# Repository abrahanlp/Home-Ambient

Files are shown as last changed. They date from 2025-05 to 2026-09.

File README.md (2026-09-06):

# Home-Ambient
 2-wire smart home thermostat with temperature, humidity, pressure and air quality measurements.

The main target is replace traditional tow wires bimetal thermostats with an intelligent one, cable to integrate with [HomeAssistance](https://www.home-assistant.io/) or works _standalone_ with custom firmware.

## 2-wire classical thermostat replacement
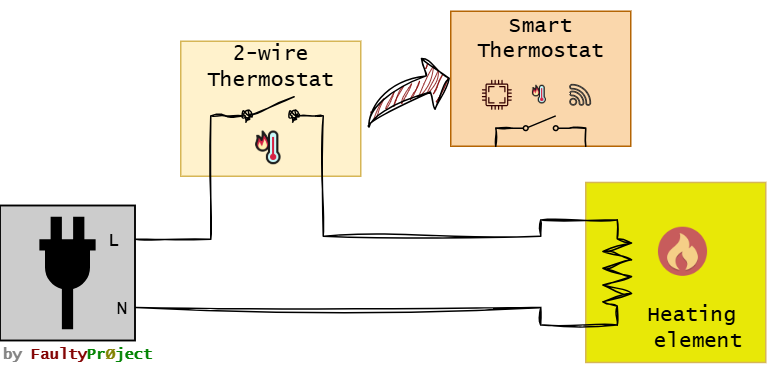
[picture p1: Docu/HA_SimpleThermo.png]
Classic two wire thermostat


### Working principle
Images below explain graphically how this system works.

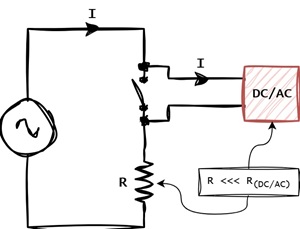
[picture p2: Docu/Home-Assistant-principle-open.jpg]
Home-Ambient principle when load is off

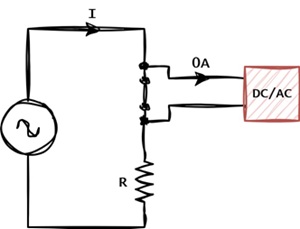
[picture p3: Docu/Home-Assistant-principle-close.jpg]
Home-Ambient principle when load is oon


The main and mandatory system requirement is a big difference between Control an Load level power. While load is some orders of magnitud above, there should not be problem, but is mandatory review every case.

# Product Requirements

| Requirement | Description  | Definition |
|:---:|:---|:---:|
| Temperature	|  Temperature measurement, with minimal interference from the device.	| ±2°C 	|
| Humidity	| Humidity measurement from ambient 	| ±5% 	|
| Air quality	| Air quality estimation by particle detection| Not defined, optional |
| Switch	| 2 pole switch	| >=10A	|
| Switch feedback	| Switch feedback to check operation | Digital or analog |
| HA | Home Assistance integration	| Mandatory	|
| Display | Optional e-Ink display	| No power relevant|
| Autonomy | Capable to operate without power	| At least 2h |

## Hardware architecture
Home-Ambient block diagram is show on image below.

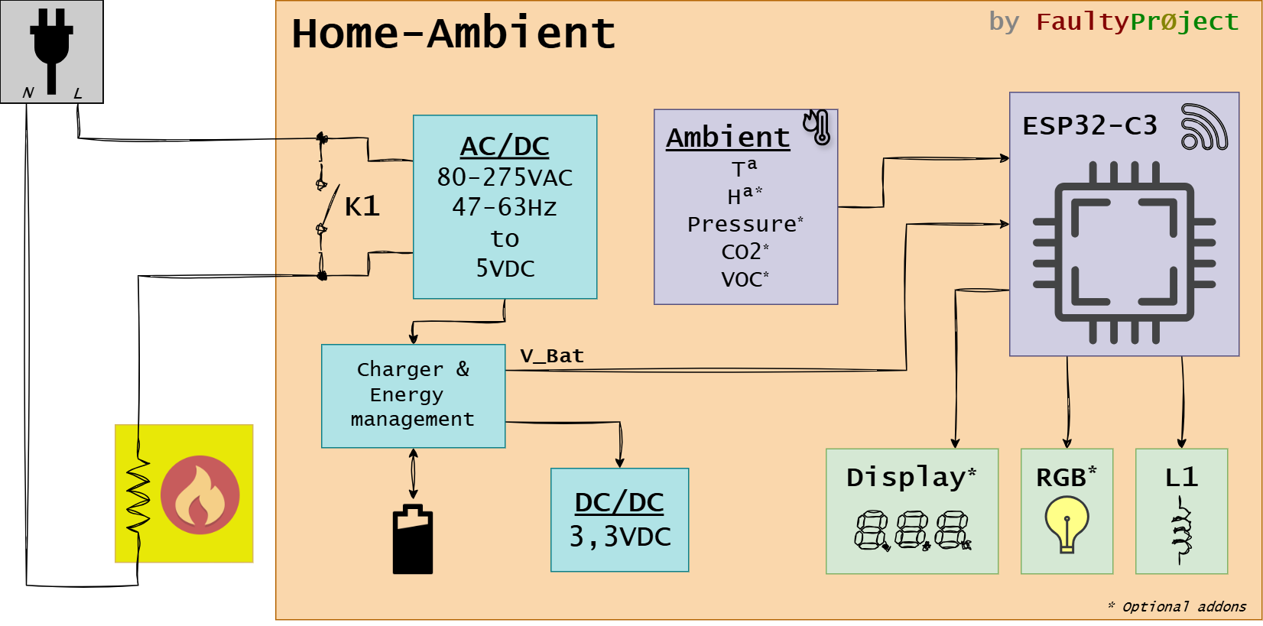
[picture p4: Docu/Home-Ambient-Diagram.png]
Home-Ambient diagram block


The PCB hardware distribution is proposed on next image.

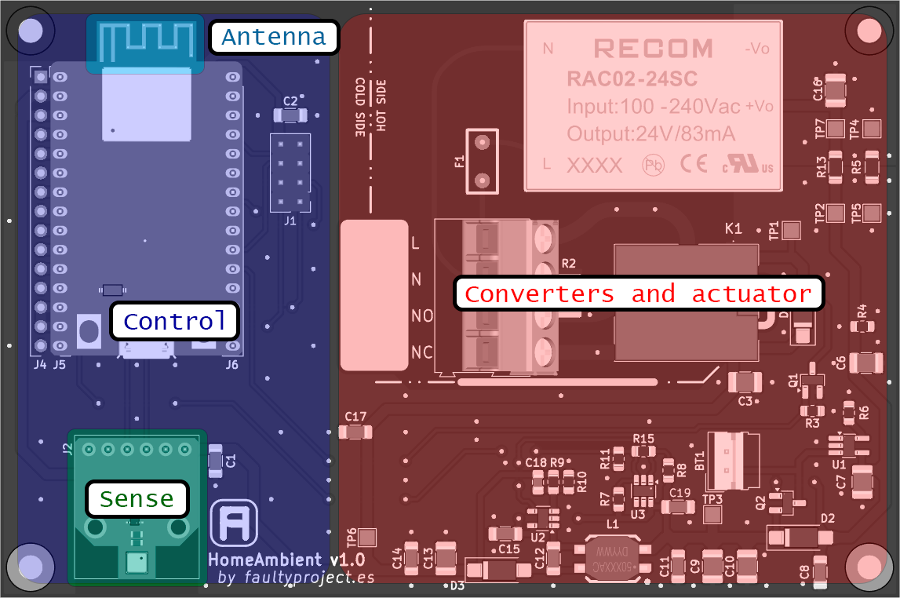
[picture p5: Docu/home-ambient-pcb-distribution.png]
Home-Ambient PCB


### Power supply, SEPIC converter
Energy when the load is activated is provided by a battery. The voltage from this power source varies from above and below 3,3V, so it is neccesary _'boost'_ and _'buck'_ converter.
Here is where the SEPIC converter comes to action, capable of manage both situations at the same time.

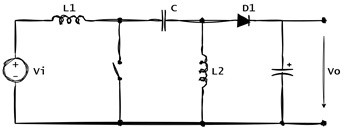
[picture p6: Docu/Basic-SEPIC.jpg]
SEPIC converter schematic


### CPU
The easiest way to integrate custom electronics on _HomeAssistant_ are the [ESPHome](https://esphome.io/) devices. This smart thermostat will be designed around classical [ESP32-C3](https://www.espressif.com/en/products/socs/esp32-c3).

### Sensors and actuators
The BME680 air quality sensor covers all requirements. More info about this component can be found on [Bosch official website](https://www.bosch-sensortec.com/en/products/environmental-sensors/gas-sensors/bme680).

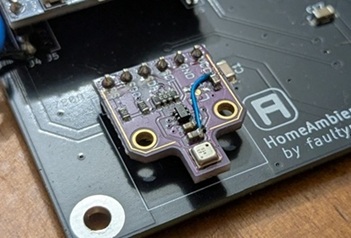
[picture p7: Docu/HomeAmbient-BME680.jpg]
BME680


## Home Assistant integration
As said before, integration is done by [ESPHome](https://esphome.io/), there is no easier way to do this.

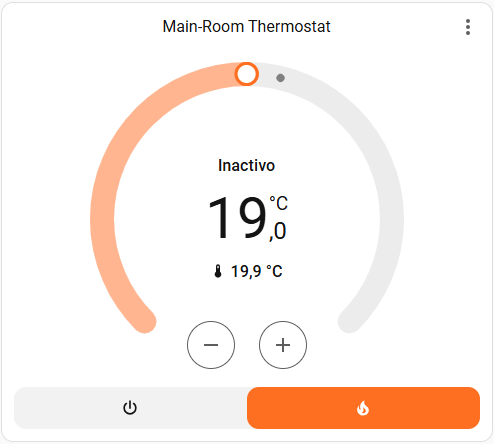
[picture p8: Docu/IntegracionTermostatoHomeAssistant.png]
Home-Ambient integration on Home Assistant


After integration on Home-Assistant, a schedule programmer is implemented using the [Niels Faber](https://github.com/nielsfaber) tools.

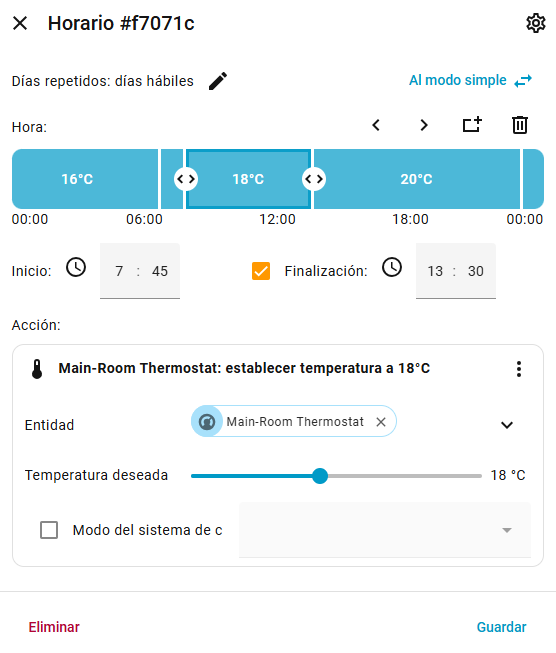
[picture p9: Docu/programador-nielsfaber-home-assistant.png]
Niels Faber scheduler programmer


# More info on [FaultyProject](https://faultyproject.es/)
If you are interested how this project was developed take a look on the next links:
 1. [Introduction](https://faultyproject.es/proyectos/home-ambient/home-ambient-intro/)
 2. [Prototype](https://faultyproject.es/proyectos/home-ambient/home-ambient-prototipo/)
 3. [Schematichs & PCB Design](https://faultyproject.es/proyectos/home-ambient/home-ambient-hardware-esquema-y-pcb/)
 4. [Home Assistant Integration](https://faultyproject.es/proyectos/home-ambient/home-ambient-integracion-con-home-assistant-y-esphome/)
 5. Case design (Future work... )

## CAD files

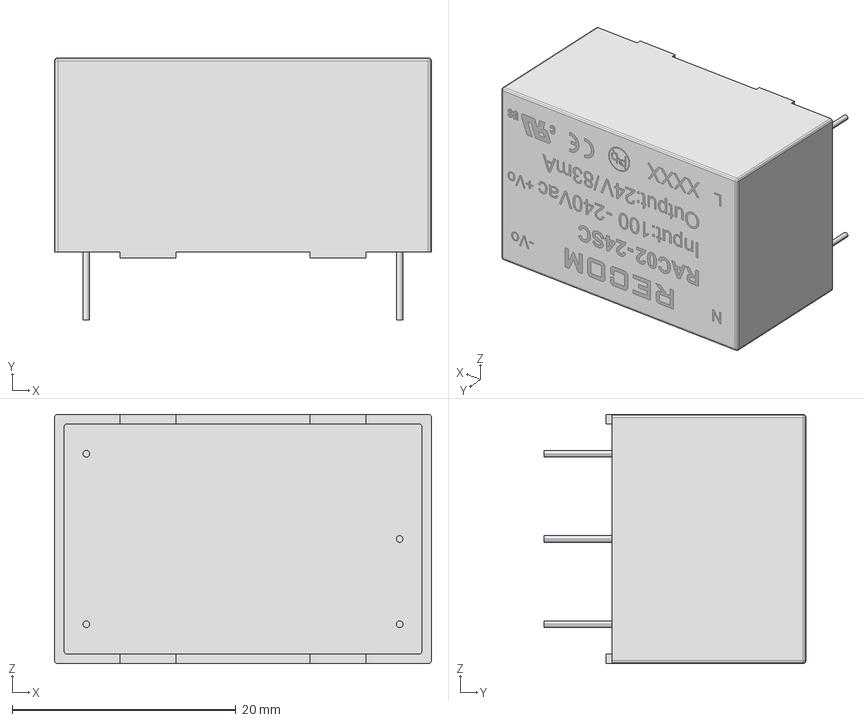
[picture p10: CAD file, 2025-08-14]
Hardware/3D_Model/rac02-05sc.stp
33.7 x 23.5 x 22.3 mm

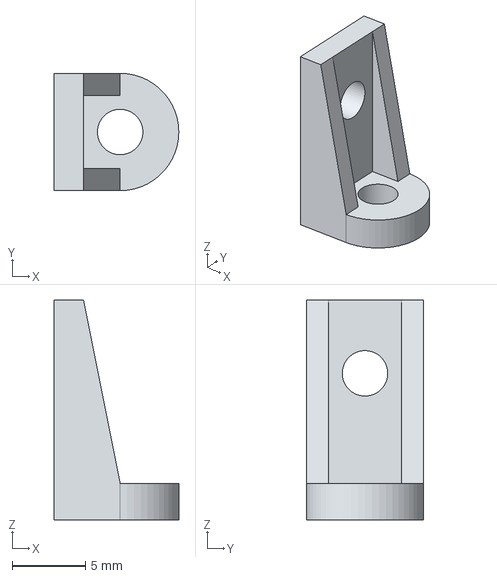
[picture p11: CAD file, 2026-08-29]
Mechanical/HomeAmbient-Fixing.step
8.50 x 8.00 x 15.0 mm

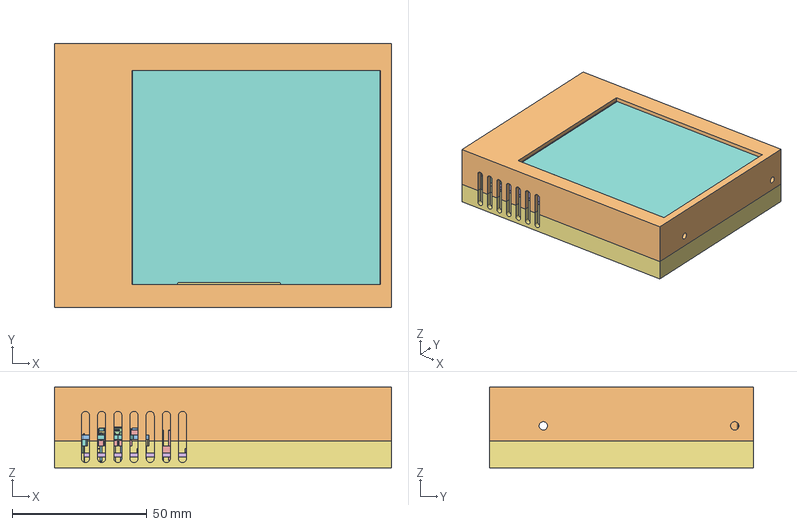
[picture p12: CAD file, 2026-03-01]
Mechanical/HomeAmbient.FCStd
125.0 x 98.0 x 30.0 mm
C_1210_3225Metric
TSOT-23-5
C_1206_3216Metric
C_1206_3216Metric001
PinHeader_2x04_P2.54mm_Vertical
C_1206_3216Metric002
R_1206_3216Metric
SOT-23
R_0805_2012Metric
rac02-05sc_1
rac02-05sc_2
rac02-05sc_3
rac02-05sc_4
rac02-05sc_5
rac02-05sc_6
C_1206_3216Metric003
C_1206_3216Metric004
C_1210_3225Metric001
C_1206_3216Metric005
C_1210_3225Metric002
R_1206_3216Metric001
C_1210_3225Metric003
C_1206_3216Metric006
BME680_PCB
BME680_PCB001
BME680_PCB002
BME680_PCB003
BME680_PCB004
BME680_PCB005
BME680_PCB006
BME680_PCB007
BME680_PCB008
BME680_PCB009
BME680_PCB010
BME680_PCB011
BME680_PCB012
BME680_PCB013
BME680_PCB014
BME680_PCB015
BME680_PCB016
BME680_PCB017
BME680_PCB018
BME680_PCB019
BME680_PCB020
BME680_PCB021
BME680_PCB022
BME680_PCB023
BME680_PCB024
BME680_PCB025
BME680_PCB026
BME680_PCB027
BME680_PCB028
BME680_PCB029
BME680_PCB030
BME680_PCB031
BME680_PCB032
BME680_PCB033
BME680_PCB034
BME680_PCB035
BME680_PCB036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

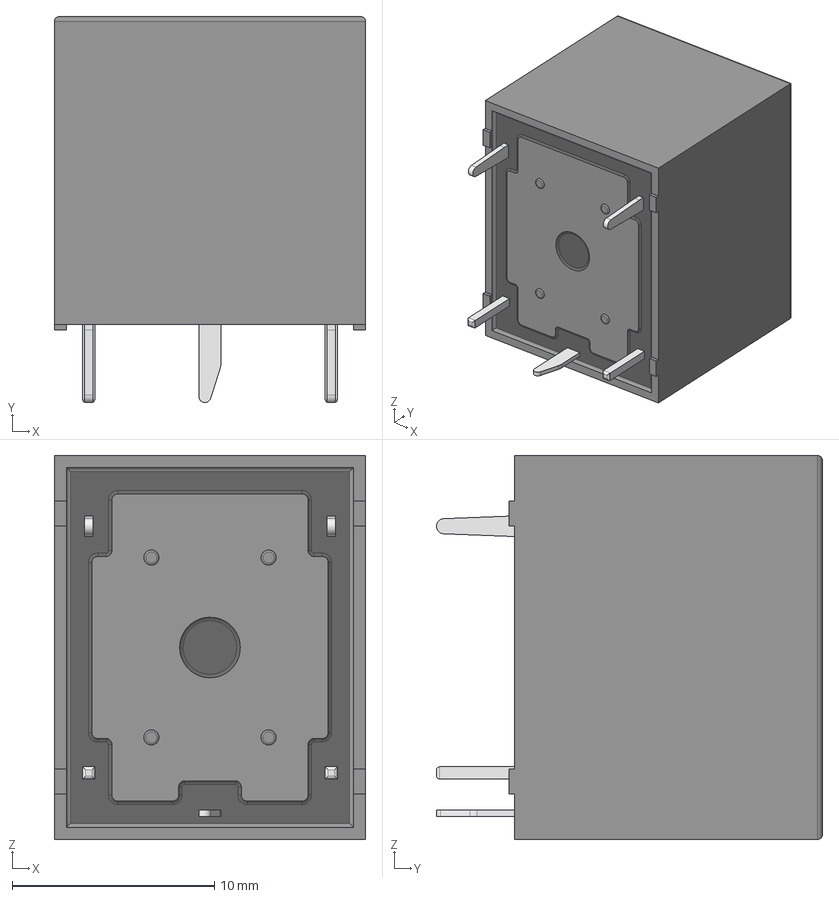
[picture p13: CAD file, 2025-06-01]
Hardware/3D_Model/J1071CS3VDC.36.stp
15.4 x 19.1 x 19.0 mm
J107_Contact Terminal x 2
J107_Common Terminal
J107_Coil Terminal x 2
J107_Body

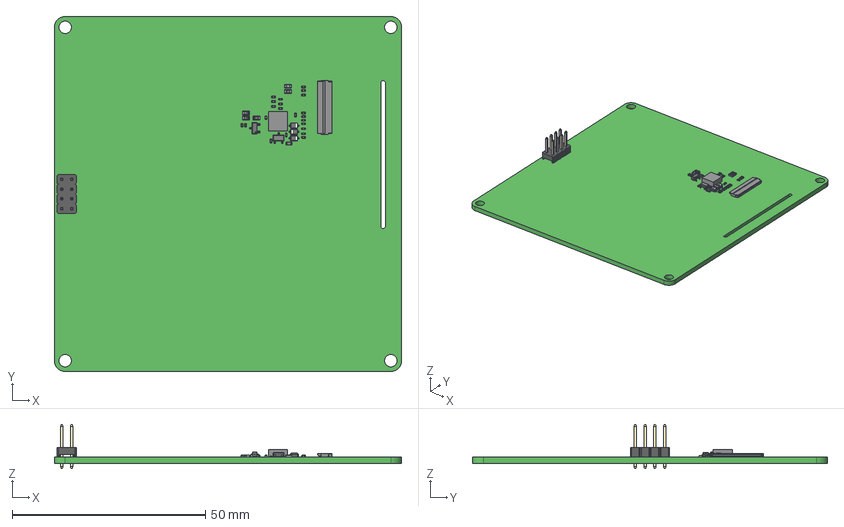
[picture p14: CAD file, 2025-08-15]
Mechanical/WeAct-EpaperModule-4.2 Board 3D.step
89.8 x 91.8 x 11.5 mm
R0603 x 5
Extruded x 6
pin_header_awl254-dg-g08d
User Library-SOT23-3
Mid_Body x 9
Mark x 9
Leader x 3
FH34SRJ-24S-0.5SH_RGB4408131
SOD323 x 3

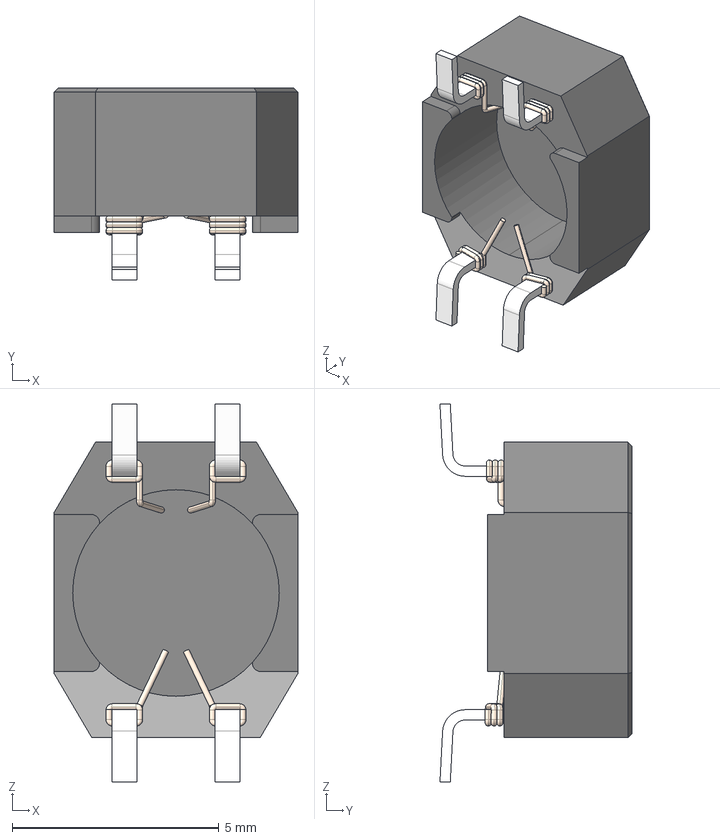
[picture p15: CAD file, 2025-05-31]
Hardware/3D_Model/5000AC.STEP
5.90 x 4.65 x 9.15 mm
mps_mag_5000AC_smt_a
mps_mag_5000AC_smt_a002
mps_mag_5000AC_smt_a003
mps_mag_5000AC_smt_a004
mps_mag_5000AC_smt_a005

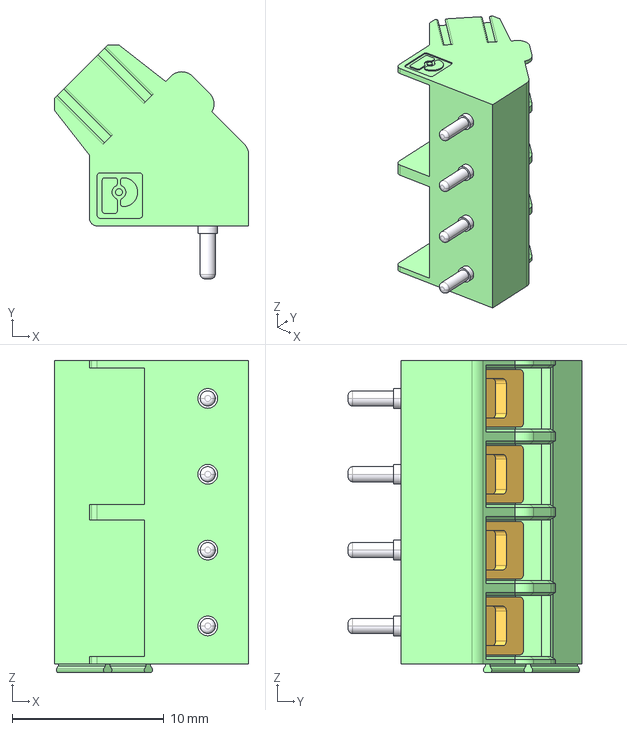
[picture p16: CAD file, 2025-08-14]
Hardware/3D_Model/1988820.stp
12.8 x 15.4 x 20.6 mm

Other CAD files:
Mechanical/HomeAmbient-Fixing.stl

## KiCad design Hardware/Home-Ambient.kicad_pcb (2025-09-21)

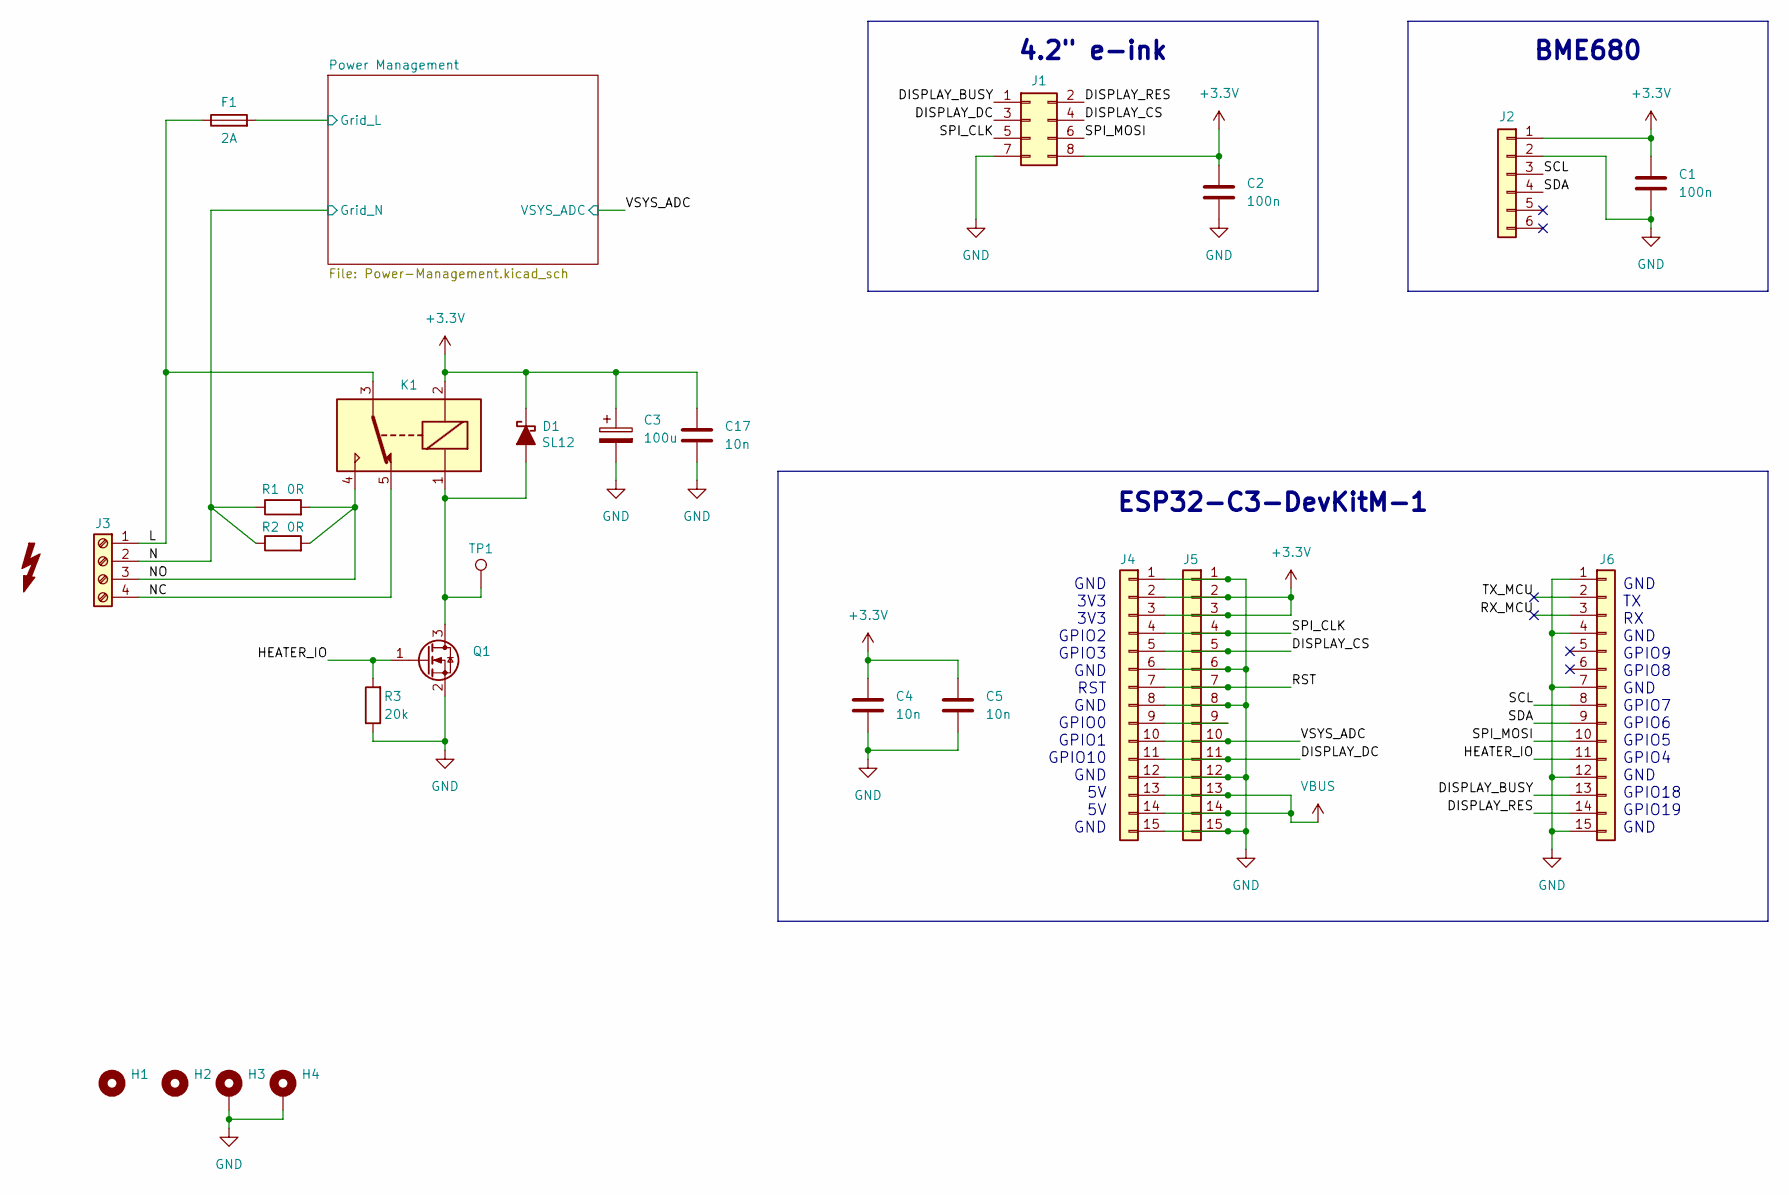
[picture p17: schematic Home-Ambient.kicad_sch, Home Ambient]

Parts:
C1, C2: 100n; C_1206_3216Metric_Pad1.33x1.80mm_HandSolder
C3: 100u; C_1210_3225Metric_Pad1.33x2.70mm_HandSolder
C4, C5, C17: 10n; C_1206_3216Metric_Pad1.33x1.80mm_HandSolder
D1: SL12; D_SMA_Handsoldering
F1: 2A; 0697H____
H1, H2: MountingHole; MountingHole_3.2mm_M3
H3, H4: MountingHole_Pad; MountingHole_3.2mm_M3_Pad_TopBottom
J1: Conn_02x05_Odd_Even; PinHeader_2x04_P2.54mm_Vertical
J2: Conn_01x06; PinHeader_1x06_P2.54mm_Vertical
J3: Screw_Terminal_01x04; TerminalBlock_Altech_AK300-4_P5.00mm
J4, J5, J6: Conn_01x15; PinHeader_1x15_P2.54mm_Vertical
K1: Relay_SPDT; J1071CS3VDC36
Q1: SSF2320Y; SOT-23_Handsoldering
R1, R2: 0R; R_1812_4532Metric_Pad1.30x3.40mm_HandSolder
R3: 20k; R_0805_2012Metric_Pad1.20x1.40mm_HandSolder
TP1: TestPoint_Pad_2.0x2.0mm

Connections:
+3.3V: C1.1, C2.1, C3.1, C4.1, C5.1, C17.1, D1.1 (K), J1.8, J2.1, J4.2, J4.3, J5.2, J5.3, K1.2; also elsewhere on the board
/DISPLAY_BUSY: J1.1, J6.13
/DISPLAY_CS: J1.4, J4.5, J5.5
/DISPLAY_DC: J1.3, J4.11, J5.11
/DISPLAY_RES: J1.2, J6.14
/HEATER_IO: J6.11, Q1.1 (G), R3.2
/L: F1.1, J3.1, K1.3
/N: J3.2, R1.1, R2.1; also elsewhere on the board
/NC: J3.4, K1.5
/NO: J3.3, K1.4, R1.2, R2.2
/Power Management/Grid_L: F1.2; also elsewhere on the board
/RST: J4.7, J5.7
/RX_MCU: J6.3
/SCL: J2.3, J6.8
/SDA: J2.4, J6.9
/SPI_CLK: J1.5, J4.4, J5.4
/SPI_MOSI: J1.6, J6.10
/TX_MCU: J6.2
/VSYS_ADC: J4.10, J5.10; also elsewhere on the board
GND: C1.2, C2.2, C3.2, C4.2, C5.2, C17.2, H3.1, H4.1, J1.7, J2.2, J4.1, J4.6, J4.8, J4.12, J4.15, J5.1, J5.6, J5.8, J5.12, J5.15, J6.1, J6.4, J6.7, J6.12, J6.15, Q1.2 (S), R3.1; also elsewhere on the board
unnamed: D1.2 (A), K1.1, Q1.3 (D), TP1.1
unnamed: J4.9, J5.9
VBUS: J4.13, J4.14, J5.13, J5.14

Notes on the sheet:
BME680
4.2" e-ink
GND TX RX GND GPIO9 GPIO8 GND GPIO7 GPIO6 GPIO5 GPIO4 GND GPIO18 GPIO19 GND
GND 3V3 3V3 GPIO2 GPIO3 GND RST GND GPIO0 GPIO1 GPIO10 GND 5V 5V GND
ESP32-C3-DevKitM-1

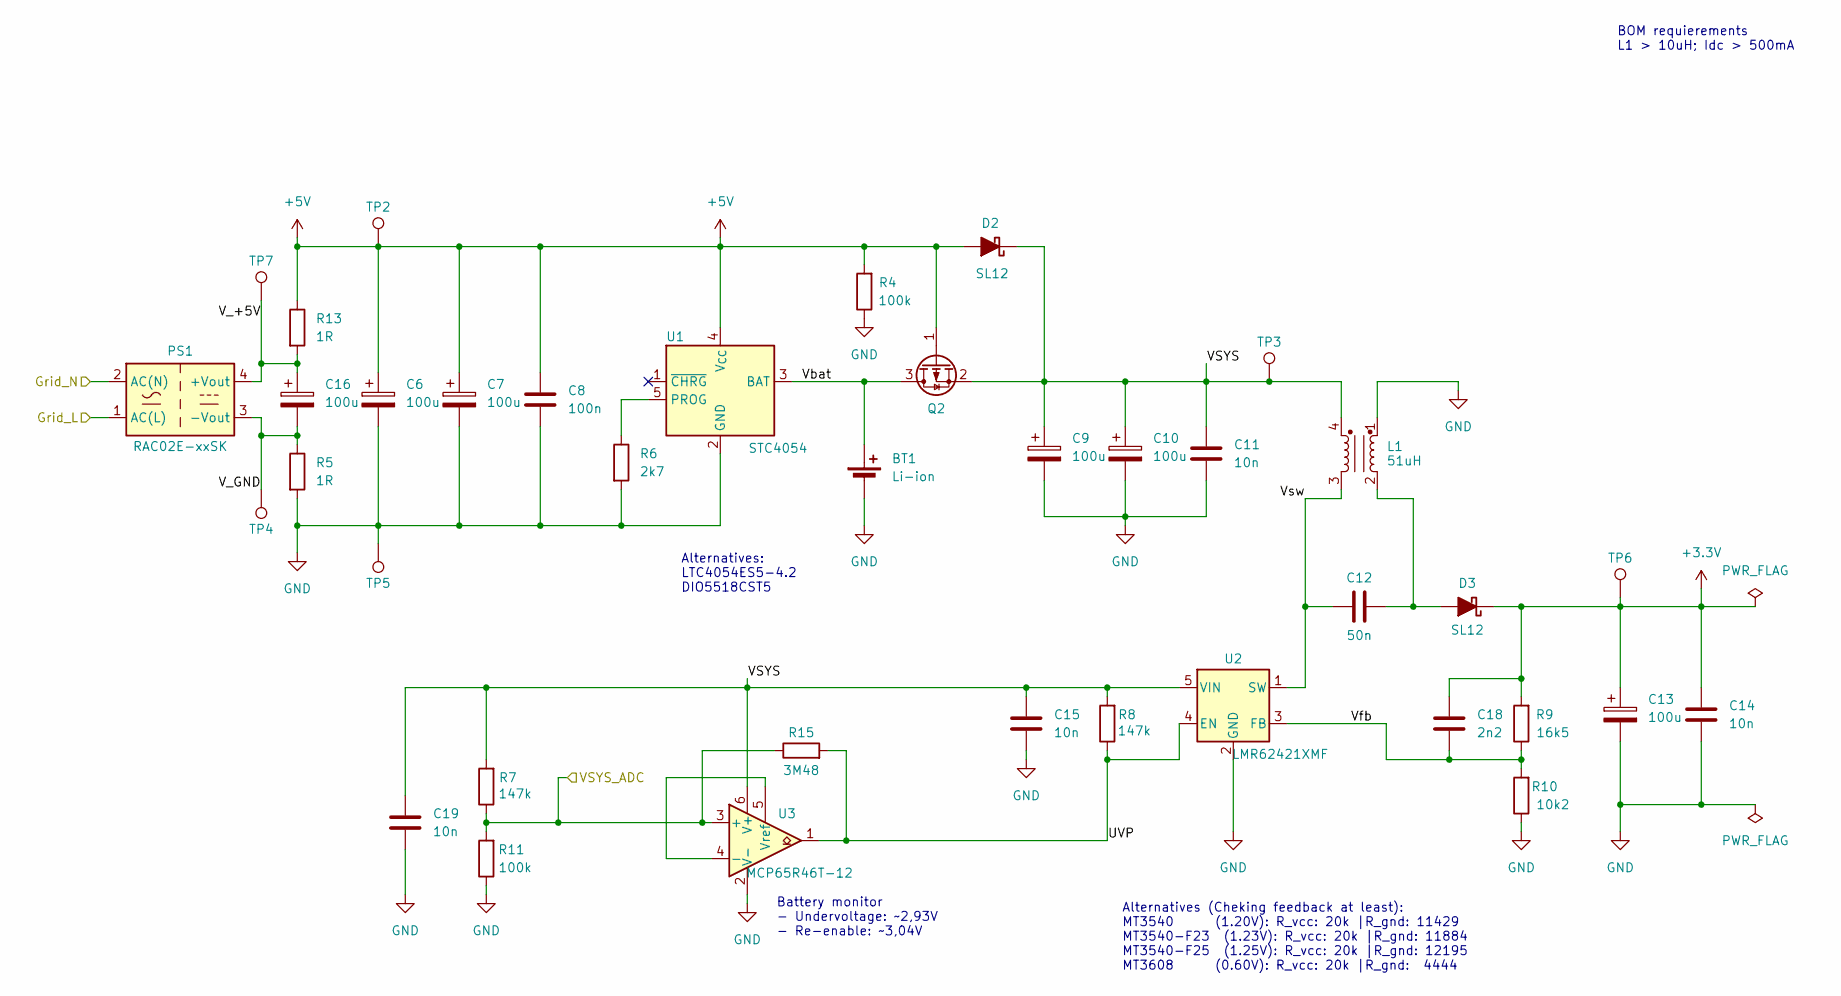
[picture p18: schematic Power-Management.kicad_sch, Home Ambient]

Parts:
BT1: Li-ion; Molex_SL_171971-0002_1x02_P2.54mm_Vertical
C6, C7, C9, C10, C13, C16: 100u; C_1210_3225Metric_Pad1.33x2.70mm_HandSolder
C8: 100n; C_1206_3216Metric_Pad1.33x1.80mm_HandSolder
C11, C14, C15, C19: 10n; C_1206_3216Metric_Pad1.33x1.80mm_HandSolder
C12: 50n; C_1206_3216Metric_Pad1.33x1.80mm_HandSolder
C18: 2n2; C_0805_2012Metric_Pad1.18x1.45mm_HandSolder
D2, D3: SL12; D_SMA_Handsoldering
L1: 51uH; Murata_5000A
PS1: RAC02E-xxSK; RAC02E-K
Q2: DMP31D1U-7; SOT-23_Handsoldering
R4, R11: 100k; R_0805_2012Metric_Pad1.20x1.40mm_HandSolder
R5, R13: 1R; R_1206_3216Metric_Pad1.30x1.75mm_HandSolder
R6: 2k7; R_0805_2012Metric_Pad1.20x1.40mm_HandSolder
R7, R8: 147k; R_0805_2012Metric_Pad1.20x1.40mm_HandSolder
R9: 16k5; R_0805_2012Metric_Pad1.20x1.40mm_HandSolder
R10: 10k2; R_0805_2012Metric_Pad1.20x1.40mm_HandSolder
R15: 3M48; R_0805_2012Metric_Pad1.20x1.40mm_HandSolder
TP2, TP3, TP4, TP5, TP6, TP7: TestPoint_Pad_2.0x2.0mm
U1: STC4054; TSOT-23-5_HandSoldering
U2: LMR62421XMF; SOT-23-5_HandSoldering
U3: MCP65R46T-12; SOT-23-6_Handsoldering

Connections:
+3.3V: C13.1, C14.1, C18.1, D3.1 (K), R9.2, TP6.1; also elsewhere on the board
+5V: C6.1, C7.1, C8.1, D2.2 (A), Q2.1 (G), R4.2, R13.1, TP2.1, U1.4 (V_{CC})
/N: PS1.2 (AC(N)); also elsewhere on the board
/Power Management/Grid_L: PS1.1 (AC(L)); also elsewhere on the board
/Power Management/UVP: R8.1, R15.2, U2.4 (EN), U3.1
/Power Management/VSYS: C9.1, C10.1, C11.1, C15.1, C19.1, D2.1 (K), L1.4, Q2.2 (S), R7.2, R8.2, TP3.1, U2.5 (VIN), U3.6 (V+)
/Power Management/V_+5V: C16.1, PS1.4 (+Vout), R13.2, TP7.1
/Power Management/V_GND: C16.2, PS1.3 (-Vout), R5.1, TP4.1
/Power Management/Vbat: BT1.1 (+), Q2.3 (D), U1.3 (BAT)
/Power Management/Vfb: C18.2, R9.1, R10.2, U2.3 (FB)
/Power Management/Vsw: C12.1, L1.3, U2.1 (SW)
/VSYS_ADC: R7.1, R11.2, R15.1, U3.3 (+); also elsewhere on the board
GND: BT1.2 (-), C6.2, C7.2, C8.2, C9.2, C10.2, C11.2, C13.2, C14.2, C15.2, C19.2, L1.1, R4.1, R5.2, R6.2, R10.1, R11.1, TP5.1, U1.2 (GND), U2.2 (GND), U3.2 (V-); also elsewhere on the board
unnamed: C12.2, D3.2 (A), L1.2
unnamed: R6.1, U1.5 (PROG)
unnamed: U3.4 (-), U3.5 (Vref)

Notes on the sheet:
Battery monitor - Undervoltage: ~2,93V - Re-enable: ~3,04V
Alternatives: LTC4054ES5-4.2 DIO5518CST5
Alternatives (Cheking feedback at least): MT3540 (1.20V): R_vcc: 20k |R_gnd: 11429 MT3540-F23 (1.23V): R_vcc: 20k |R_gnd: 11884 MT3540-F25 (1.25V): R_vcc: 20k |R_gnd: 12195 MT3608 (0.60V): R_vcc: 20k |R_gnd: 4444
BOM requierements L1 > 10uH; Idc > 500mA

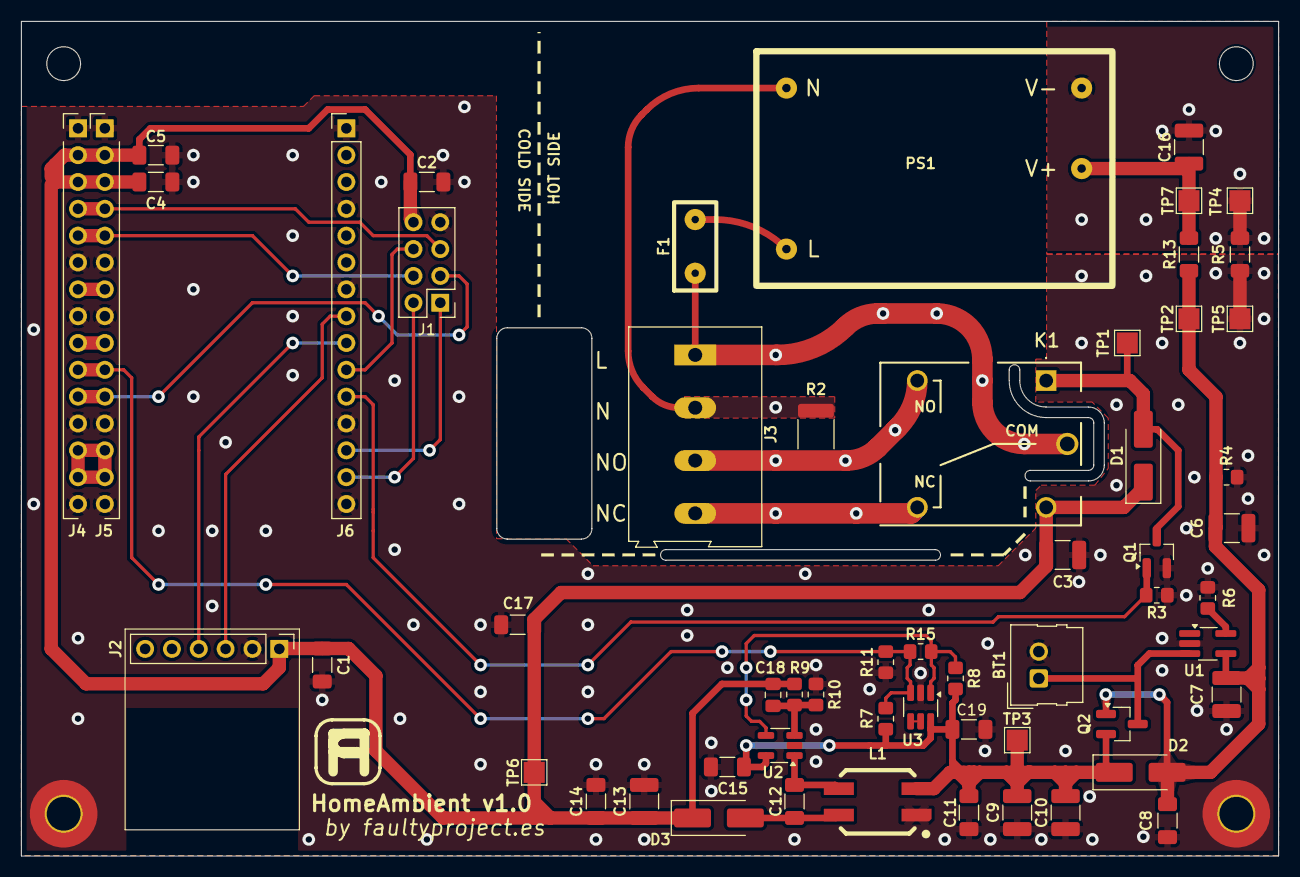
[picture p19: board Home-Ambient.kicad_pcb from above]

Board: 2 copper layers, 119.0 x 79.0 mm, 62 parts (1 on the bottom side), 32 nets.

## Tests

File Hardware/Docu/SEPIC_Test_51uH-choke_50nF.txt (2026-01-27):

Von 3
Voff 2.9

#Relay
Vin;Iin;Vo;Io
3.0;0.169;3.28;0.112
3.2;0.158;3.28;0.112
3.5;0.145;3.28;0.113
4.0;0.128;3.28;0.113
4.5;0.115;3.28;0.114
5.0;0.106;3.28;0.114
5.5;0.098;3.28;0.114

#13ohm
Vin;Iin;Vo;Io
3.00;0.404;3.28;0.226
3.05;0.395;3.28;0.226
3.5;0.333;3.28;0.226
4.0;0.285;3.28;0.226
4.5;0.250;3.28;0.226
5.0;0.224;3.28;0.226
5.5;0.204;3.28;0.226

#6.5ohm
Vin;Iin;Vo;Io
4.5;0.680;3.28;0.480
5.0;0.565;3.28;0.480
5.5;0.551;3.28;0.480

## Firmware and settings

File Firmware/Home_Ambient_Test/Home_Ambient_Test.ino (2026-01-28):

#include <Wire.h>
#include <Adafruit_Sensor.h>
#include "Adafruit_BME680.h"
#include <Adafruit_NeoPixel.h>

const int rgb_pin = 8;
const int relay_pin = 4;
const int temp_adc_pin = 0;
const int sys_adc_pin = 1;
const int bme_sda = 6;
const int bme_scl = 7;

Adafruit_NeoPixel rgb_led(1, rgb_pin, NEO_GRB + NEO_KHZ800);
bool rgb_on = false;
byte rgb_r = 0;
byte rgb_g = 0;
byte rgb_b = 0;

TwoWire i2c = TwoWire(0);

Adafruit_BME680 bme(&i2c);

void setup() {
  //Set RGB on ESP32-C3 module
  rgb_led.begin();
  rgb_led.setPixelColor(0, rgb_led.Color(0, 0, 0));
  rgb_led.setBrightness(63);

  //Set power monitor
  pinMode(temp_adc_pin, INPUT);
  pinMode(sys_adc_pin, INPUT);

  //Set relay
  pinMode(relay_pin, OUTPUT);
  digitalWrite(relay_pin, LOW);

  //Set serial port
  Serial.begin(115200);
  while(!Serial);
  Serial.println("Home Ambient ESP32 Arduino Test");

  //Set BME680
  i2c.begin(bme_sda, bme_scl, 400000);
  if (!bme.begin()) {
      Serial.println("BME680 sensor not found");
  }else{
    bme.setTemperatureOversampling(BME680_OS_8X);
    bme.setHumidityOversampling(BME680_OS_2X);
    bme.setPressureOversampling(BME680_OS_4X);
    bme.setIIRFilterSize(BME680_FILTER_SIZE_3);
    bme.setGasHeater(320, 150);
  }
}

void loop() {
  bme.beginReading();
  int temp_mV = analogReadMilliVolts(temp_adc_pin);
  int sys_mV = analogReadMilliVolts(sys_adc_pin);

  if(rgb_on){
    rgb_led.setPixelColor(0, rgb_led.Color(rgb_r, rgb_g, rgb_b));
    rgb_led.show();

    if(rgb_b){
      rgb_b += 85;
      if(rgb_b == 255){
        rgb_b = 0;
      }
    }else{
      if(rgb_g){
        rgb_g += 85;
        if(rgb_g == 255){
          rgb_g = 0;
          rgb_b = 85;
        }
      }else{
        rgb_r += 85;
        if(rgb_r == 255){
          rgb_r = 0;
          rgb_g = 85;
        }
      }
    }
  }
  
  if(Serial.available()) {
    byte rx_char = Serial.read();
    switch(rx_char) {
      case 'R':
      case 'r':
        digitalWrite(relay_pin, HIGH);
        Serial.println("Relay ON");
        break;
      case 'L':
      case 'l':
        rgb_led.setPixelColor(0, rgb_led.Color(0, 0, 0));
        rgb_led.show();
        if(rgb_on == false){
          rgb_on = true;
        }else{
          rgb_on = false;
        }
        break;
      default:
        Serial.print(rx_char);
        digitalWrite(relay_pin, LOW);
        break;
    }
  }

  delay(50);

  Serial.print("Temp(mV):");   Serial.print(temp_mV);    Serial.print(",");
  Serial.print("Sys(mV):");     Serial.print(sys_mV);     Serial.print(",");

  if (bme.endReading()) {
    Serial.print("T2(C):");     Serial.print(bme.temperature);             Serial.print(",");
    Serial.print("P(hPa):");    Serial.print(bme.pressure / 100.0);        Serial.print(",");
    Serial.print("H(%):");      Serial.print(bme.humidity);                Serial.print(",");
    Serial.print("Gas(kOhm):"); Serial.print(bme.gas_resistance / 1000.0); //Serial.print(",");
  }

  //Serial.print("R:"); Serial.print(rgb_r); Serial.print(",");
  //Serial.print("G:"); Serial.print(rgb_g); Serial.print(",");
  //Serial.print("B:"); Serial.print(rgb_b);
  
  Serial.println("");

  delay(450);
}

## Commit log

2024-11-23 Basic Arduino hardware test
    [Home-Ambient.kicad_pcb, Home-Ambient.kicad_sch]
2025-04-06 HW to KiCAD 9. Added library components
    [Home-Ambient.kicad_sch]
2025-04-14 RECOM footprint. Pinhead footprints.
    [Home-Ambient.kicad_sch]
2025-04-16 Updated sch.
    [Home-Ambient.kicad_sch]
2025-04-18 SEPIC script Octave.
    [Home-Ambient.kicad_sch, Power-Management.kicad_sch]
2025-04-19 Basic SEPIC circuit for calculations. Li-ion charger.
    [Home-Ambient.kicad_sch, Power-Management.kicad_sch]
2025-04-30 Basic SEPIC calculations.
    [Power-Management.kicad_sch]
2025-05-02 SEPIC first components value approach. SEPIC calculations corrections.
    [Power-Management.kicad_sch]
2025-05-03 FP Sheet. Voltage feedback and undervoltage detection.
    [Home-Ambient.kicad_sch, Power-Management.kicad_sch]
2025-05-03 ESP32 connections
    [Home-Ambient.kicad_sch]
2025-05-04 Fixed R1 and R2 uv calculation. Current measure resistor en GND power source.
    [Home-Ambient.kicad_sch, Power-Management.kicad_sch]
2025-05-30 Complete schematics
    [Home-Ambient.kicad_sch, Power-Management.kicad_sch]
2025-05-31 Common mode inductor symbol, footprint
    [5000AC.STEP, Home-Ambient.kicad_sch, Power-Management.kicad_sch]
2025-06-01 Common mode footprint pin fix and silkscreen
2025-06-01 Symbol, footprint and 3D model relay
    [Home-Ambient.kicad_sch, J1071CS3VDC.36.stp, Power-Management.kicad_sch]
2025-06-03 BOM completed
    [Home-Ambient.kicad_sch, Power-Management.kicad_sch]
2025-06-05 Added optional power source
    [Power-Management.kicad_sch]
2025-06-12 ZP05SXX00WB footprint
    [Power-Management.kicad_sch]
2025-06-15 Fuse and main connector footprints. ERC check.
    [Home-Ambient.kicad_sch, Power-Management.kicad_sch]
2025-07-03 Moved SEPIC controller supply from battery to power commuter.
    [Home-Ambient.kicad_pcb, Power-Management.kicad_sch]
2025-07-04 PCB progress
    [Home-Ambient.kicad_pcb, Power-Management.kicad_sch]
2025-07-06 New 100uF capacitor package.
    [Home-Ambient.kicad_pcb, Home-Ambient.kicad_sch, Power-Management.kicad_sch]
2025-07-20 PCB delimitation. Optional 5V Power supply removed because size constraint.
    [Home-Ambient.kicad_pcb, Power-Management.kicad_sch]
2025-08-07 Mounting holes and PCB progress.
    [Home-Ambient.kicad_pcb, Home-Ambient.kicad_sch, Power-Management.kicad_sch]
2025-08-08 Fixed references. Parallel resistor on thermostat connection config.
    [Home-Ambient.kicad_pcb, Home-Ambient.kicad_sch, Power-Management.kicad_sch]
2025-08-10 Equalizing output power supply impedance.
    [Home-Ambient.kicad_pcb, Power-Management.kicad_sch]
2025-08-10 PCB Progress.
    [Home-Ambient.kicad_pcb, Power-Management.kicad_sch]
2025-08-12 Grounding pending. DRU file added.
    [Home-Ambient.kicad_pcb]
2025-08-13 Ground planes
    [Home-Ambient.kicad_pcb]
2025-08-13 Crossing tracks on 90 degrees. Rework on Grid Power tracks
    [Home-Ambient.kicad_pcb]
2025-08-13 Replaced main and battery supply switch transistor reference.
    [Home-Ambient.kicad_pcb, Power-Management.kicad_sch]
2025-08-13 First PCB draft finished.
    [Home-Ambient.kicad_pcb]
2025-08-13 Vias placing. 10nF added on 3V relay PDN
    [Home-Ambient.kicad_pcb, Home-Ambient.kicad_sch]
2025-08-13 Vias refinement.
    [Home-Ambient.kicad_pcb]
2025-08-13 Warning and instrucction silkscreens.
    [Home-Ambient.kicad_pcb]
2025-08-14 Add and set 3D models.
    [1988820.stp, Home-Ambient.kicad_pcb, rac02-05sc.stp]
2025-08-15 Basic 3D files.
    [Home-Ambient.kicad_pcb, HomeAmbient.FCStd, WeAct-EpaperModule-4.2 Board 3D.step]
2025-08-16 Added PCB dimmensions
    [Home-Ambient.kicad_pcb, HomeAmbient.FCStd]
2025-08-16 Case progress
    [HomeAmbient.FCStd]
2025-08-17 Enclosure main parts finished.
    [HomeAmbient.FCStd]
2025-08-17 Removed soldermask over power tracks. Relay footprint edit for silkscreen margin.
    [Home-Ambient.kicad_pcb]
2025-08-29 BOM updated, SEPIC regulator replaced.
    [Home-Ambient.kicad_sch, Power-Management.kicad_sch]
2025-08-29 SEPIC footprint fixed.
    [Home-Ambient.kicad_pcb]
2025-09-02 Added battery undervoltage circuit.
    [Home-Ambient.kicad_pcb, Home-Ambient.kicad_sch, Power-Management.kicad_sch]
2025-09-04 Comparator simulation
    [Power-Management.kicad_sch]
2025-09-06 Schematic and BOM updated with new undervoltage protection.
    [Home-Ambient.kicad_pcb, Power-Management.kicad_sch]
2025-09-07 Closed PCB layout
    [Home-Ambient.kicad_pcb]
2025-09-07 Check DRU
    [Home-Ambient.kicad_pcb]
2025-09-17 Final BOM
    [Home-Ambient.kicad_pcb, Home-Ambient.kicad_sch, Power-Management.kicad_sch]
2025-09-21 Production files
    [Home-Ambient-B_Cu.gbl, Home-Ambient-B_Mask.gbs, Home-Ambient-B_Paste.gbp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]
2025-11-12 Docu update. GPIO0 ADC removed on yaml file
2025-11-25 Voltage system gain and unit update.
2026-01-09 Bottom case
    [HomeAmbient.FCStd]
2026-01-11 Basic case
    [HomeAmbient.FCStd]
2026-01-11 Display hole
    [HomeAmbient.FCStd]
2026-01-14 PCB holder height
    [HomeAmbient.FCStd]
2026-01-15 Added fix mounting part
    [HomeAmbient.FCStd]
2026-01-15 Fix part names
    [HomeAmbient.FCStd]
2026-01-15 PCB mounting hole
    [HomeAmbient.FCStd]
2026-01-16 M2.5 Nut hole
    [HomeAmbient.FCStd]
2026-01-18 Bottom nuts pattern and display height
    [HomeAmbient.FCStd]
2026-01-18 Mounting holes on top part
    [HomeAmbient.FCStd]
2026-01-21 RGB turn on red on heat_action
2026-01-21 BOM. Increased SEPIC output from 3,285 to 3,326.
    [Power-Management.kicad_sch]
2026-01-27 Test Arduino sketch modified to last hardware. - Removing UV sensor - Adding redundant temperature sensor - BMS voltaje now is system voltaje
2026-03-01 Increased venting holes size and increased by one.
    [HomeAmbient.FCStd]
2026-03-01 Added display place helper
    [HomeAmbient.FCStd]
2026-03-05 Update notes about SEPIC feedback resistors.
    [Power-Management.kicad_sch]
2026-08-29 Fixing production files
    [HomeAmbient-Fixing.step, HomeAmbient-Fixing.stl]
2026-09-06 Update case design status in README
